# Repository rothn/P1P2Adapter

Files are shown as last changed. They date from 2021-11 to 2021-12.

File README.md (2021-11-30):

# Interface PCB for HomeBus®-based Devices

Ever wonder what A/C systems talk about? Have a HomeBus®-based system like P1P2? Satisfy your curiosity and reward yourself with a fun and challenging project! Build or send away for one of these from your favorite PCB manufacturer, and enjoy direct access to your system. The possibilities are vast!

## Key Features
- Read from and optionally write to your HomeBus® (i.e., the stream of data running between parts of your A/C system and/or other HomeBus®-based devices)
- Power an Arduino Uno and companion devices (e.g., ESP8266) directly from your pre-existing wiring (i.e., the two wires coming out of the wall and going into the thermostat) instead of spending time on complicated power management features for battery operation
- Enjoy fully-specified KiCad files and an MIT license, empowering you to tweak or integrate this design into your own projects

## Specs and Validation
Based on reference design from MAX22088 datasheet, which is optimized for 57.6kbps. Observed to operate correctly on a system running at 9600bps over multi-hour burn-in test.

# Usage

## Warning
Using this device may damage your HomeBus® system! Check with your doctor to see if Tinkering is right for you. In my experiments, I tested everything the best that I could before using it and I suggest that you do the same. Also, note that this involves connection to AC wiring (the HomeBus®). Be careful with that step, as it can be dangerous.

## PCB Creation / Sourcing

### PCB Manufacturer
As of 2021, I paid $5 for 5 boards plus $15 for shipping from PCBWay, and at least one tested OK.

1. Export gerber files from KiCad and send them to your PCB manufacturer. Most have specific requirements for options in the export process. For PCBWay, find these [here](https://www.pcbway.com/blog/help_center/Generate_Gerber_file_from_Kicad_5_1_6.html).
2. Upload the zip file and select the correct tolerances on your PCB manufacturer's website. See the "design rules" menu in KiCad for these. Be sure to run a design rules check in the PCB editor just to double-check that you have the right options. Also be sure to select the correct number of vias, etc. The automated system is likely to catch errors, but getting things wrong here might slow down the process and affect your quoted price.
3. For anything not in the design rules, I highly recommend selecting the cheapest option.

Note: Most manufacturers can also populate the board with components, but this will be an extra cost. DIY'ing it can be fun and cheaper with the proper tools (hot air tool, soldering iron with small tip). Your manufacturer of choice will likely have this option on their website.

### At-Home (Guidelines)
There are people who are experts at this. Refer to their advice (Google around). Take the suggestions below with a grain of salt, but above all else, please keep in mind the inherent danger of working with chemicals at home:

The PCB can be manufactured with an at-home process by printing onto high-quality acetate compatible with your printer, UV exposure onto a presensitized, double-sided PCB, development, and etching. Toner transfer is unlikely to work due to the tolerances involved. CNC milling is also an option.

## Connection to Arduino Uno

### Software
I recommend the [P1P2Serial](https://github.com/Arnold-n/P1P2Serial) Arduino-compatible C++ library to interact with the HomeBus®. The included P1P2Serial library is a great interface tool. The P1P2 monitor example may be a helpful starting point for its ability to dump out packets from the bus as raw hex to the Arduino's USB serial device. Keep in mind that the decoding logic may not make sense for your specific device.

### Hardware
My test configuration is as follows. To allow writing to the bus, drive the RST pin on the interface board to GND instead of +5V.

- Connect J2 to Positive (sometimes called P1) and J3 to Neutral (sometimes called P2) on the HomeBus®. These are likely interchangeable, but I have not validated this in practice. See termination section of schematic (bottom-left).
- +12V -> Arduino Vin
- +5V -> 1k resistor -> interface board RST (this disables output, move input to GND to enable)
- GND -> Arduino GND
- VLOGIC -> Arduino +5V
- DOUT -> Arduino8* ||** (20kOhm resistor -> Arduino GND)
- DIN -> NC***

\*: Arduino labeled input "8" in "Digital PWM" section (Port B, Input 0 of ATmega328p)\
\*\*: Shorthand notation for "in parallel with"\
\*\*\*: Shorthand for "no connect" -- the data input is not connected to anything since writing to the bus is disabled

Notes (__Important__)
- The maximum load on +12V is 200mA, per the MAX22088 spec
- Do not use +5V for anything that draws more than 70 milliamps, and do not use it at all for external loads if using +12V
- I have found +12V outputs a very noisy 12V DC in my particular application, but the spec says that 7.3V is typical, without listing a maximum.

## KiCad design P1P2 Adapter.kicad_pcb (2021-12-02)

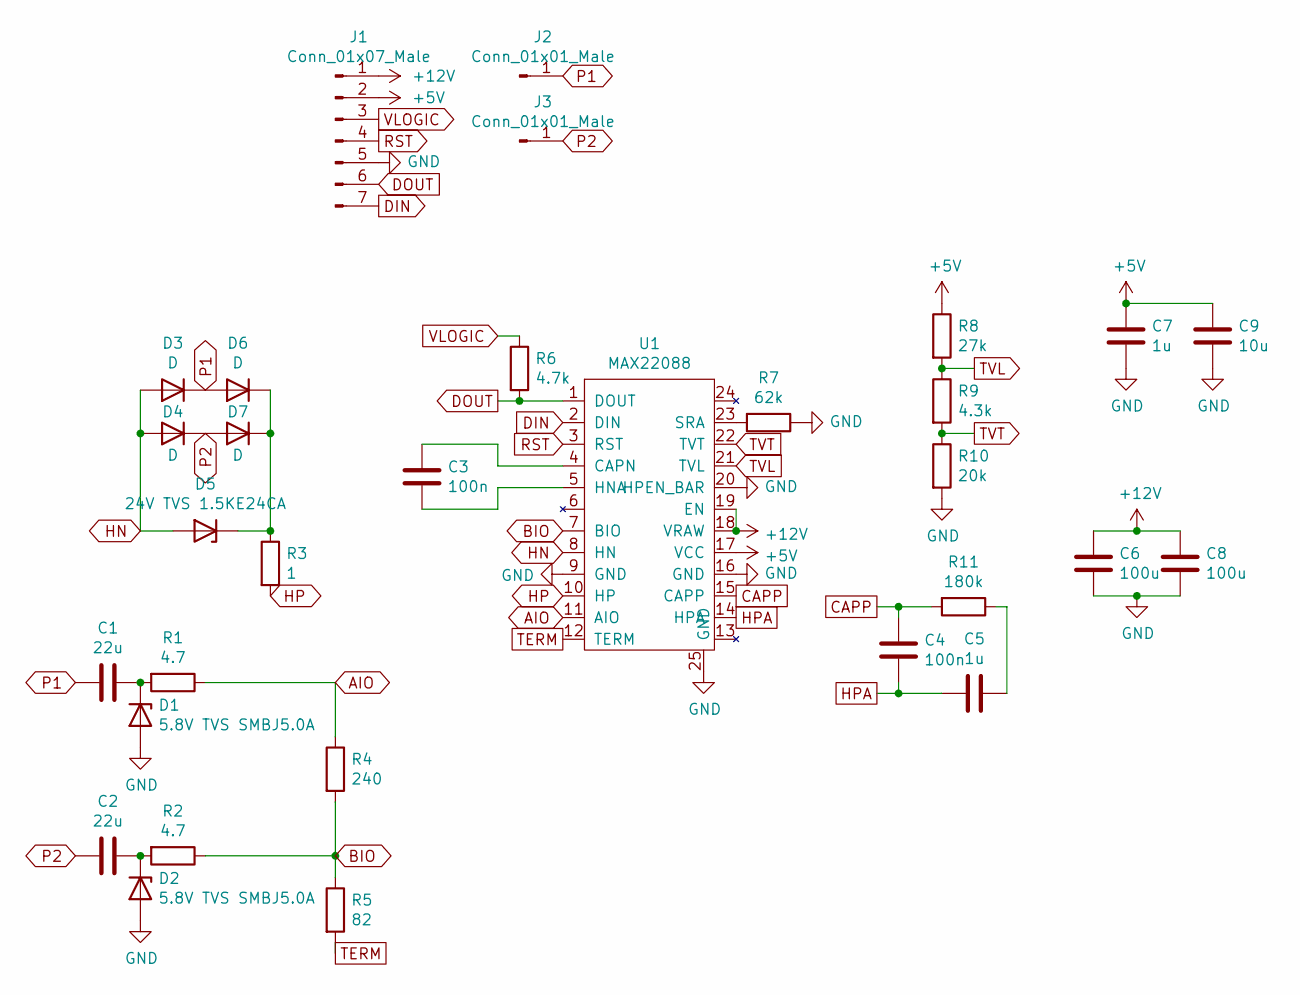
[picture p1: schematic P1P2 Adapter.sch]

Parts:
C1, C2: 22u; C_1206_3216Metric_Pad1.33x1.80mm_HandSolder
C3, C4: 100n; C_1206_3216Metric_Pad1.33x1.80mm_HandSolder
C5, C7: 1u; C_1206_3216Metric_Pad1.33x1.80mm_HandSolder
C6, C8: 100u; C_1206_3216Metric_Pad1.33x1.80mm_HandSolder
C9: 10u; C_1206_3216Metric_Pad1.33x1.80mm_HandSolder
D1, D2: 5.8V TVS SMBJ5.0A; D_SMB_Handsoldering
D3, D4, D6, D7: D; D_P600_R-6_P12.70mm_Horizontal
D5: 24V TVS 1.5KE24CA; D_DO-201_P12.70mm_Horizontal
J1: Conn_01x07_Male; PinHeader_1x07_P2.54mm_Vertical
J2, J3: Conn_01x01_Male; PinHeader_1x01_P2.54mm_Vertical
R1, R2: 4.7; R_1206_3216Metric_Pad1.30x1.75mm_HandSolder
R3: 1; R_1206_3216Metric_Pad1.30x1.75mm_HandSolder
R4: 240; R_1206_3216Metric_Pad1.30x1.75mm_HandSolder
R5: 82; R_1206_3216Metric_Pad1.30x1.75mm_HandSolder
R6: 4.7k; R_1206_3216Metric_Pad1.30x1.75mm_HandSolder
R7: 62k; R_1206_3216Metric_Pad1.30x1.75mm_HandSolder
R8: 27k; R_1206_3216Metric_Pad1.30x1.75mm_HandSolder
R9: 4.3k; R_1206_3216Metric_Pad1.30x1.75mm_HandSolder
R10: 20k; R_1206_3216Metric_Pad1.30x1.75mm_HandSolder
R11: 180k; R_1206_3216Metric_Pad1.30x1.75mm_HandSolder
U1: MAX22088; TQFN-24-1EP_4x4mm_P0.5mm_EP2.8x2.8mm_PullBack

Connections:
+5V: C7.1, C9.1, J1.2, R8.1, U1.17 (VCC)
+12V: C6.1, C8.1, J1.1, U1.18 (VRAW), U1.19 (EN)
AIO: R1.1, R4.1, U1.11 (AIO)
BIO: R2.1, R4.2, R5.1, U1.7 (BIO)
CAPP: C4.1, R11.2, U1.15 (CAPP)
DIN: J1.7, U1.2 (DIN)
DOUT: J1.6, R6.2, U1.1 (DOUT)
GND: C6.2, C7.2, C8.2, C9.2, D1.2 (A), D2.2 (A), J1.5, R7.1, R10.2, U1.9 (GND), U1.16 (GND), U1.20 (HPEN_BAR), U1.25 (GND)
HN: D3.2 (A), D4.2 (A), D5.2 (A), U1.8 (HN)
HP: R3.2, U1.10 (HP)
HPA: C4.2, C5.2, U1.14 (HPA)
unnamed: C1.2, D1.1 (K), R1.2
unnamed: C2.2, D2.1 (K), R2.2
unnamed: C3.1, U1.4 (CAPN)
unnamed: C3.2, U1.5 (HNA)
unnamed: C5.1, R11.1
unnamed: D5.1 (K), D6.1 (K), D7.1 (K), R3.1
unnamed: R7.2, U1.23 (SRA)
P1: C1.1, D3.1 (K), D6.2 (A), J2.1
P2: C2.1, D4.1 (K), D7.2 (A), J3.1
RST: J1.4, U1.3 (RST)
TERM: R5.2, U1.12 (TERM)
TVL: R8.2, R9.1, U1.21 (TVL)
TVT: R9.2, R10.1, U1.22 (TVT)
VLOGIC: J1.3, R6.1

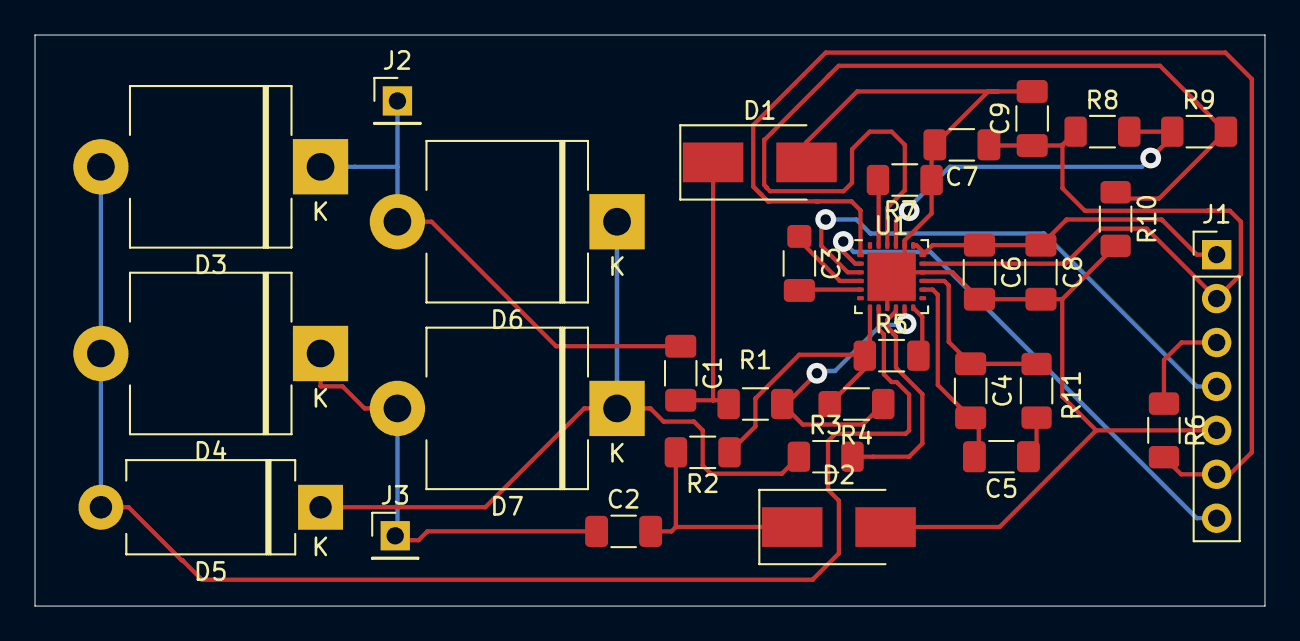
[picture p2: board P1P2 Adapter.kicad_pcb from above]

Board: 2 copper layers, 71.1 x 33.0 mm, 31 parts (0 on the bottom side), 25 nets.

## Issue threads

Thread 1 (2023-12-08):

Over heating issue

dzungpv, 2023-12-08:
@rothn I follow your design but the MAX22088 very hot when I only use 10ma (both 5V and 12V), and it shutdown after 10 minutes. Do you have this problem or you using external heat-sink?

dzungpv, 2023-12-09:
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

I measure the voltage it is 16V, Some time it is 17v or 18v. I also try to use more the VRAW through DC/DC with an ESP-32 module, it draw max 150ma (I measure power in the bus), it is super hot. I have 4 boards and all the same.
The C1 and C2 I use 22uF/50v polarized capacitor, other component I like TVS I use parts from MAX22088EVKIT: https://www.analog.com/media/en/technical-documentation/data-sheets/MAX22088EVKIT.pdf. It still warm if I am not connect the transceiver to anything.

dzungpv, 2024-01-16:
@rothn I have found the issue, compare to the EVKIT, they use 2.7k pull up resistor to the logic voltage but you are not, so it make the the chip very hot and consume high current (180ma) and could not use. Yours may work but later chip revision they change it. This cost me $200 for the EVKIT and times to found out the issue.

Closed 2024-01-22.

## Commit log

2021-09-15 Updated ground plane and PCB design
    [P1P2 Adapter.dsn, P1P2 Adapter.kicad_pcb, P1P2 Adapter.sch]
2021-11-28 Final touches, incl. design rule checks before having the board manufactured
    [P1P2 Adapter.kicad_pcb]
2021-11-30 Fixed incorrect trim resistors and termination resistors. Credit goes to Arnold N, creator of P1P2Serial
    [P1P2 Adapter.kicad_pcb, P1P2 Adapter.sch]
2021-12-02 Made changes for 9600bps operation
    [P1P2 Adapter.kicad_pcb, P1P2 Adapter.sch]
